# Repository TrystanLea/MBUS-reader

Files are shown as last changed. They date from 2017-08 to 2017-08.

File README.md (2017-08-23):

# M-Bus reader
to go with [emonTX](https://github.com/openenergymonitor/emontx3)

Part of [OpenEnergyMonitor.org](https://openenergymonitor.org) project.

This board allows you to read data from M-bus module in the heat meter. 

The Meter-Bus(M-Bus) is a low cost bus system for remote reading and powering utility meters. It is also the European Standard. 

Circuit diagram used is from [here](https://github.com/rscada/libmbus/tree/master/hardware).
mbus_levelshifter

The 34V is provided to the circuit through a [DC to DC voltage step up boost converter](http://www.ebay.co.uk/itm/XL6009-DC-DC-Voltage-Step-Up-Boost-Converter-replace-LM2577-3-32v-input-UK-Fast-/400858208676). 

## Schematic
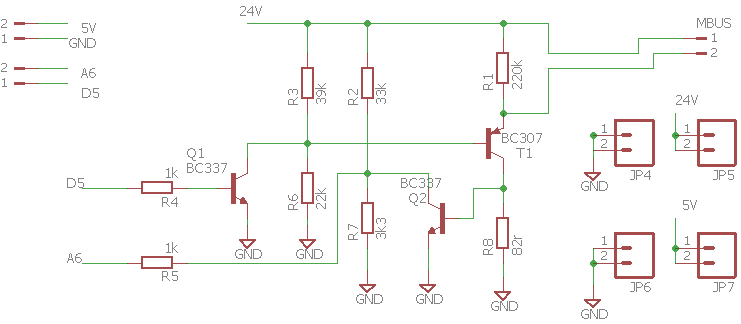
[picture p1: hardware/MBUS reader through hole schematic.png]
mbus surface mount schematic

## Board 
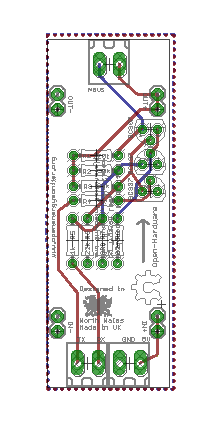
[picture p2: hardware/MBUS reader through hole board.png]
mbus surface mount board


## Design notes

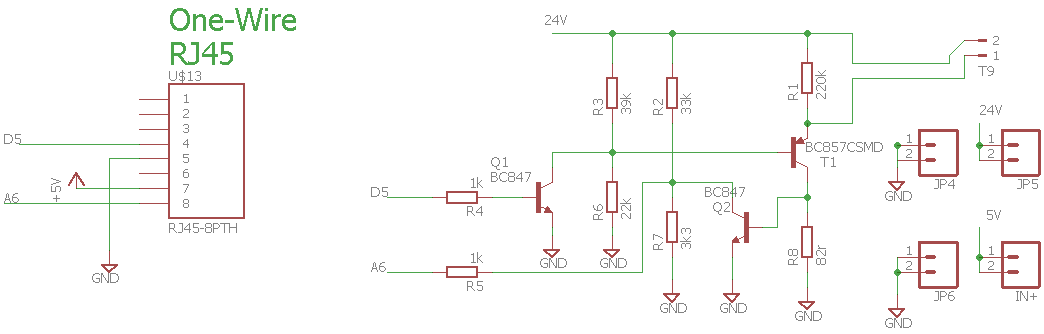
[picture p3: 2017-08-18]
hardware/MBUS reader surface mount schematic.png

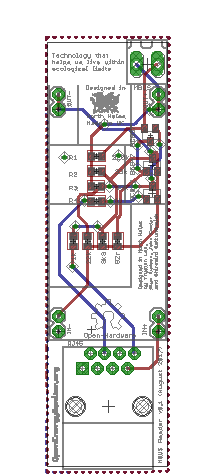
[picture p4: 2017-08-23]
hardware/MBUS reader surface mount board.png

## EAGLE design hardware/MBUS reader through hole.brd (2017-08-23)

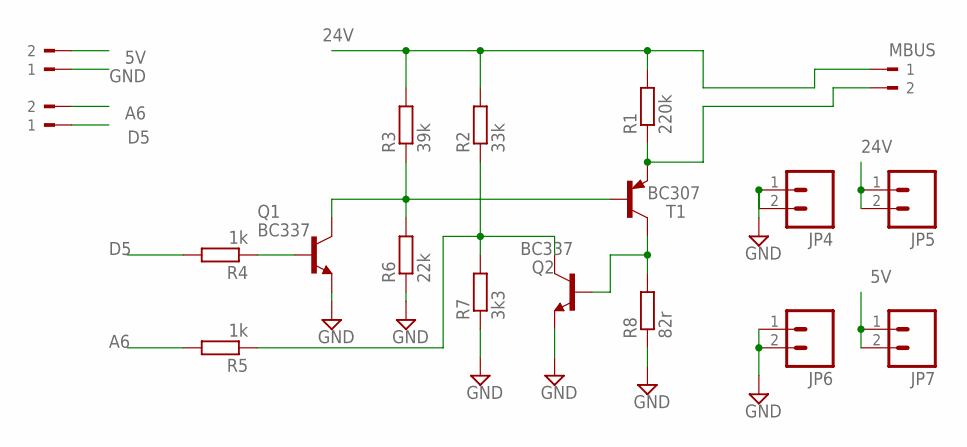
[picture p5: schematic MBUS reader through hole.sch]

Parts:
JP4, JP5, JP6, JP7: M02PTH; 1X02
MBUS, MBUS1, MBUS2: 180-2
Q1, Q2: BC337; TO92
R1: 220k; 0204/7
R2: 33k; 0204/7
R3: 39k; 0204/7
R4, R5: 1k; 0204/7
R6: 22k; 0204/7
R7: 3k3; 0204/7
R8: 82r; 0204/7
T1: BC307; TO92

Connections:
5V: JP7.1, JP7.2, MBUS2.2
24V: JP5.1, JP5.2, MBUS.1, R1.2, R2.2, R3.2
A6: MBUS1.2, R5.2
D5: MBUS1.1, R4.2
GND: JP4.1, JP4.2, JP6.1, JP6.2, MBUS2.1, Q1.1 (E), Q2.1 (E), R6.1, R7.1, R8.1
unnamed: MBUS.2, R1.1, T1.1 (E)
unnamed: Q2.2 (B), R8.2, T1.3 (C)
unnamed: Q1.3 (C), R3.1, R6.2, T1.2 (B)
unnamed: Q2.3 (C), R2.1, R5.1, R7.2
unnamed: Q1.2 (B), R4.1

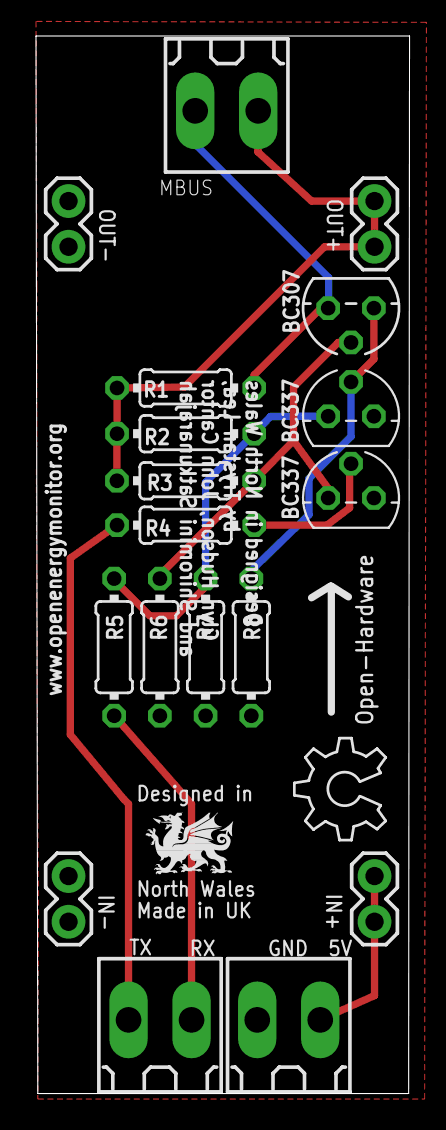
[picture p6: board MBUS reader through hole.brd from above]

Board: 2 copper layers, 20.8 x 58.8 mm, 19 parts (0 on the bottom side), 10 nets.

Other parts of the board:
LOGO1: OSHW_LOGO_6MILX0200-NT; OSHW_6X200_NOTEXT

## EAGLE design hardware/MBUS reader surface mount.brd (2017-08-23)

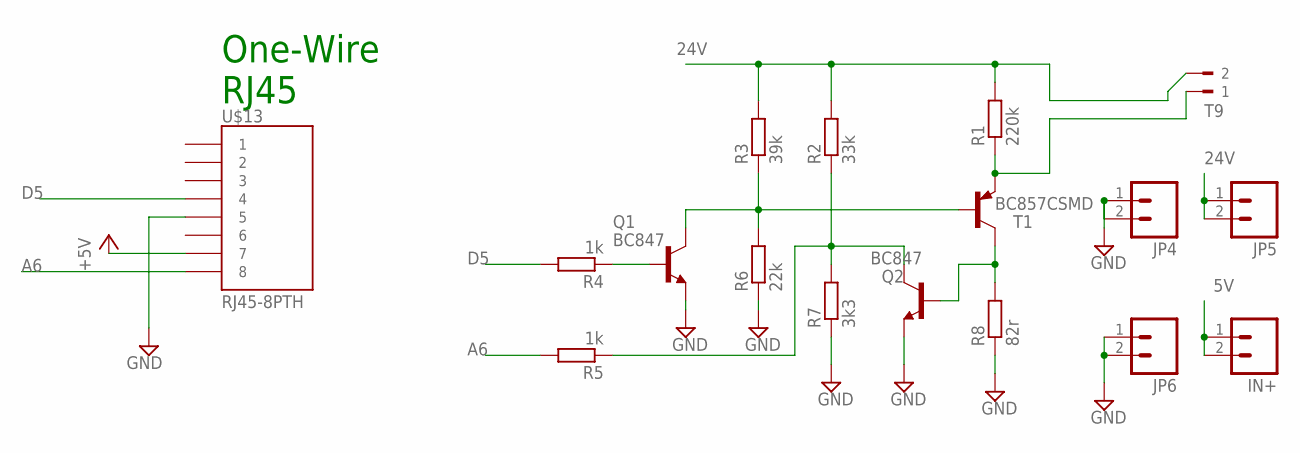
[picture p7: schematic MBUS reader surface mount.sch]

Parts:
IN+: M02PTH; 1X02
JP4, JP5, JP6: M02PTH; 1X02
Q1, Q2: BC847; SOT23
R1: 220k; R0603
R2: 33k; R0603
R3: 39k; R0603
R4, R5: 1k; R0603
R6: 22k; R0603
R7: 3k3; R0603
R8: 82r; R0603
T1: BC857CSMD; SOT23-BEC
T9: 180-2
U$13: RJ45-8PTH; RJ45-8

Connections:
5V: IN+.1, IN+.2, U$13.7
24V: JP5.1, JP5.2, R1.2, R2.2, R3.2, T9.2
A6: R5.2, U$13.8
D5: R4.2, U$13.4
GND: JP4.1, JP4.2, JP6.1, JP6.2, Q1.2 (E), Q2.2 (E), R6.1, R7.1, R8.1, U$13.5
unnamed: R1.1, T1.E, T9.1
unnamed: Q2.1 (B), R8.2, T1.C
unnamed: Q1.3 (C), R3.1, R6.2, T1.B
unnamed: Q2.3 (C), R2.1, R5.1, R7.2
unnamed: Q1.1 (B), R4.1

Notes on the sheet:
One-Wire RJ45

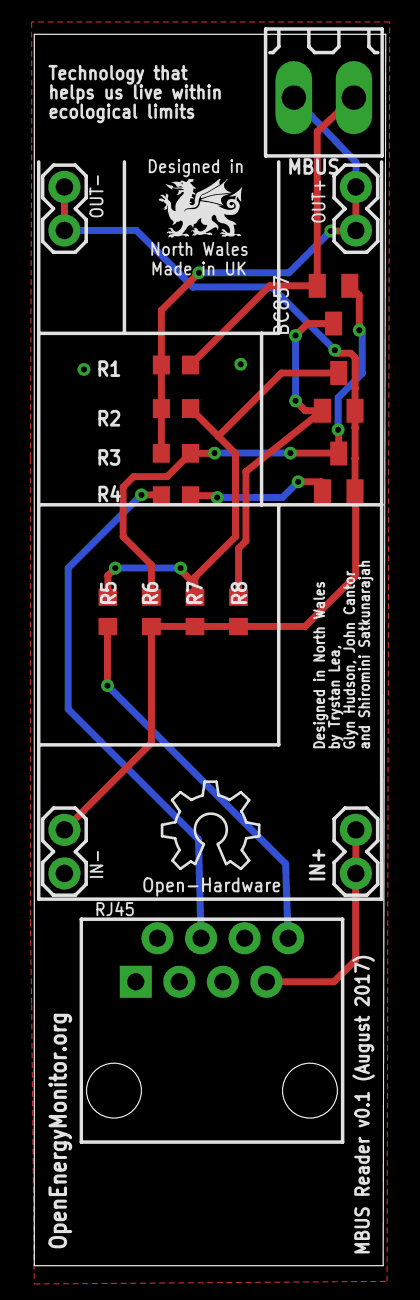
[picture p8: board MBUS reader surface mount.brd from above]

Board: 2 copper layers, 20.5 x 71.8 mm, 18 parts (0 on the bottom side), 10 nets.

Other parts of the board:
LOGO1: OSHW_LOGO_6MILX0200-NT; OSHW_6X200_NOTEXT

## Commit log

2017-08-09 added Eagle and Gerber files
    [MBUS reader surface mount V0.1.brd, MBUS reader surface mount V0.1.sch, MBUS reader through hole V.0.1.brd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]
2017-08-09 hardware folder sorted
    [MBUS reader surface mount V0.1.brd, MBUS reader surface mount V0.1.sch, MBUS reader through hole V.0.1.brd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]
2017-08-16 modified files
    [MBUS reader through hole.brd, MBUS reader through hole.sch]
2017-08-16 name changes
    [MBUS reader surface mount.brd, MBUS reader surface mount.sch, MBUS reader through hole.brd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]
2017-08-23 through hole with connector blocks
    [MBUS reader surface mount.brd, MBUS reader through hole.brd, MBUS reader through hole.sch]

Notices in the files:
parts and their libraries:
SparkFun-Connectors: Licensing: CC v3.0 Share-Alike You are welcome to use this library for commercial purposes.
